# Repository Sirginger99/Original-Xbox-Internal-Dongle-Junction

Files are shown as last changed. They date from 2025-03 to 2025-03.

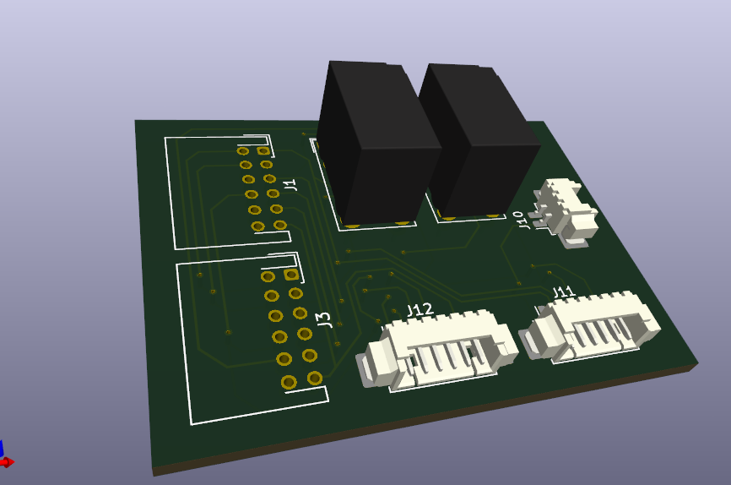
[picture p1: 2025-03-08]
beta/Capture.PNG

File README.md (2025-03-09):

Open source project creating a juntion to use for internalizing 
Xbox(OG) dongles. For those unfamiliar, this will allow you to 
internalize a dongle while retaining use of the controller port. 
It's a simple relay circuit that will switch to controller if 
one is plugged in, and default on the dongle if the controller 
is not in use. The goal was to make something simple, cheap, 
and small. There have been many variations of this that use 
switches, programmed chips, and spliced wires. This design 
removes the need for any of those. Please note that these are 
designed for one internal dongle per port. Stacking multiple 
dongles onto the same port may require a switch or additional 
materials. The materials document lists everything used on the 
PCB, along with it's matching connectors.

The pin positions are identical on the "Mobo" and "Controllers" 
connectors. This requires a cross cable be used from the "Mobo" 
connector to the motherboard. The controllers plug dirctly to the 
junction.

The "Shield" connector is for grounding the shields of 
the controller ports. The ports themselves will need to be 
insulated from the Xbox's metal cage. It is also necessary to 
verify that the connector on the controller itself has been 
grounded. While some aftermarket controllers may already be 
grounded, others will require some solder on the black wire to the
metal shield.

The "Xerc" connector are for those who have a Xerc 2 mod and wish
to internalize a dvd dongle. The wire that would normally bridge 
the two can just be plugged into the marked pin. This is connected
to both dongle positions.

For those unable to view the materials file, a picture is attached below.
Materials

Revision 1. 
Dimensions: 55 x 33.5 x 13.4mm. 
The difference between this and beta is a designated spot for the 
diodes. Originally, they would have been soldered across the points. 
This design was changed for complete assembly upon ordering, and an 
attempt to ease the mounting process by including all parts on the 
same side of the pcb.
Capture4
Photo Mar 03 2025, 5 23 53 PM

Revision 2. 
Dimensions: 40 x 35.5 x 13.4mm. 
All the same features as revision 1, just slightly smaller.
rev2

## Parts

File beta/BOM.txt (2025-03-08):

G5V-1-T90 DC5	2	relay
S12B-PHDSS		2	12pin connector
0532610671		2	6pin connector
0532610271		1	2pin connector

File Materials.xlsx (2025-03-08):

Comments | Position | Manufature# | JLCPCB# | Digikey# | Connector
Mobo,Controllers | J1, J2 | S12B-PHDSS(LF)(SN) | C161673 | 455-S12B-PHDSS-ND | PHDR-12VS
Dongles | J3, J4 | 532610671 | C99277 | WM7624CT-ND | 510210600
Xerc,Shield | J5, J6 | 532610271 | C177225 | WM7620CT-ND | 510210200
Relay | K1, K2 | G5V-1 DC5 | C28695 | 39-G5V-1DC5-ND
Diode | D1, D2 | 1N4004 | C3058 | 1N4004DICT-ND

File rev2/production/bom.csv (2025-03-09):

Designator | Footprint | Quantity | Value | LCSC Part #
D1, D2 | D_DO-41_SOD81_P10.16mm_Horizontal | 2 | 1N4004
J1 | JST_PHD_S12B-PHDSS_2x06_P2.00mm_Horizontal | 1 | Mobo
J2 | JST_PHD_S12B-PHDSS_2x06_P2.00mm_Horizontal | 1 | Controllers
J3 | Molex_PicoBlade_53261-0671_1x06-1MP_P1.25mm_Horizontal | 1 | Dongle1
J4 | Molex_PicoBlade_53261-0671_1x06-1MP_P1.25mm_Horizontal | 1 | Dongle2
J5 | Molex_PicoBlade_53261-0271_1x02-1MP_P1.25mm_Horizontal | 1 | Shield
J6 | Molex_PicoBlade_53261-0271_1x02-1MP_P1.25mm_Horizontal | 1 | Xerc
K1, K2 | Relay_SPDT_Omron_G5V-1 | 2 | G5V-1

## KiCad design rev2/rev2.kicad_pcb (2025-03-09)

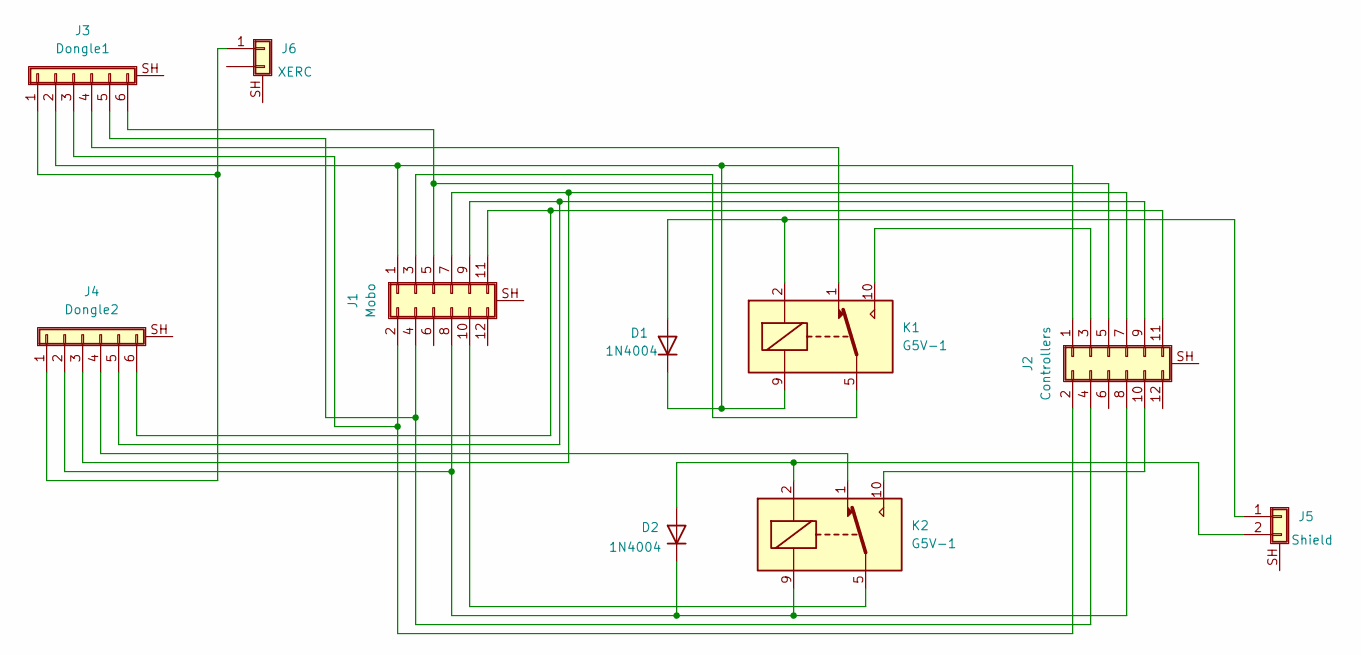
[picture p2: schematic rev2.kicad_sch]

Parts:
D1, D2: 1N4004; D_DO-41_SOD81_P10.16mm_Horizontal
J1: Mobo; JST_PHD_S12B-PHDSS_2x06_P2.00mm_Horizontal
J2: Controllers; JST_PHD_S12B-PHDSS_2x06_P2.00mm_Horizontal
J3: Dongle1; Molex_PicoBlade_53261-0671_1x06-1MP_P1.25mm_Horizontal
J4: Dongle2; Molex_PicoBlade_53261-0671_1x06-1MP_P1.25mm_Horizontal
J5: Shield; Molex_PicoBlade_53261-0271_1x02-1MP_P1.25mm_Horizontal
J6: Xerc; Molex_PicoBlade_53261-0271_1x02-1MP_P1.25mm_Horizontal
K1, K2: G5V-1; Relay_SPDT_Omron_G5V-1

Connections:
unnamed: D1.2 (A), J5.1, K1.2
unnamed: D1.1 (K), J1.1, J2.1, J3.2, K1.9
unnamed: D2.2 (A), J5.2, K2.2
unnamed: D2.1 (K), J1.8, J2.8, J4.2, K2.9
unnamed: J1.2, J2.2, J3.3
unnamed: J1.3, K1.5, K1.6
unnamed: J1.4, J2.4, J3.5
unnamed: J1.5, J2.5, J3.6
unnamed: J1.7, J2.7, J4.3
unnamed: J1.9, J2.9, J4.5
unnamed: J1.10, K2.5, K2.6
unnamed: J1.11, J2.11, J4.6
unnamed: J2.3, K1.10
unnamed: J2.10, K2.10
unnamed: J3.1, J4.1, J6.1
unnamed: J3.4, K1.1
unnamed: J4.4, K2.1

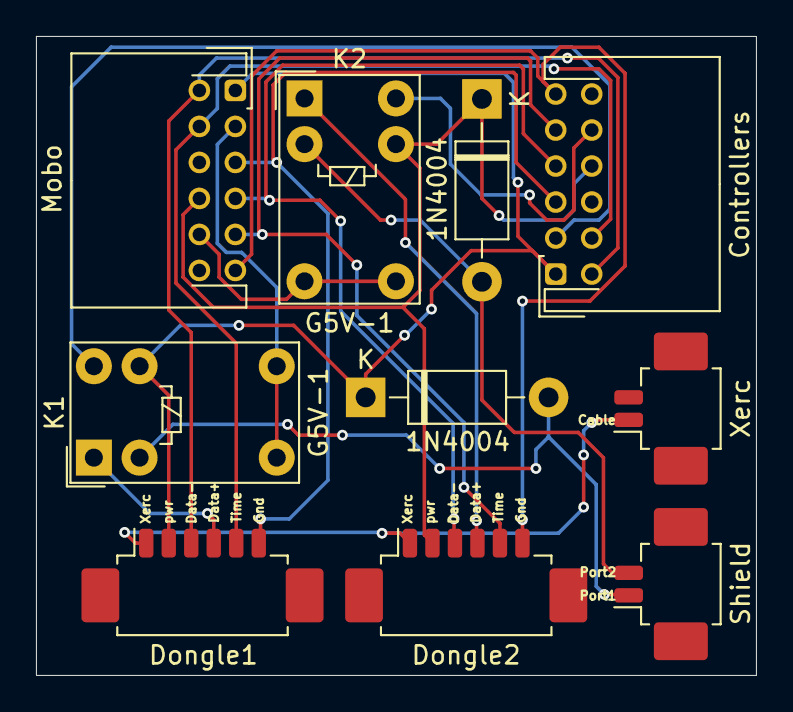
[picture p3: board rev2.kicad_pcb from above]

Board: 2 copper layers, 40.0 x 35.5 mm, 10 parts (0 on the bottom side), 17 nets.
